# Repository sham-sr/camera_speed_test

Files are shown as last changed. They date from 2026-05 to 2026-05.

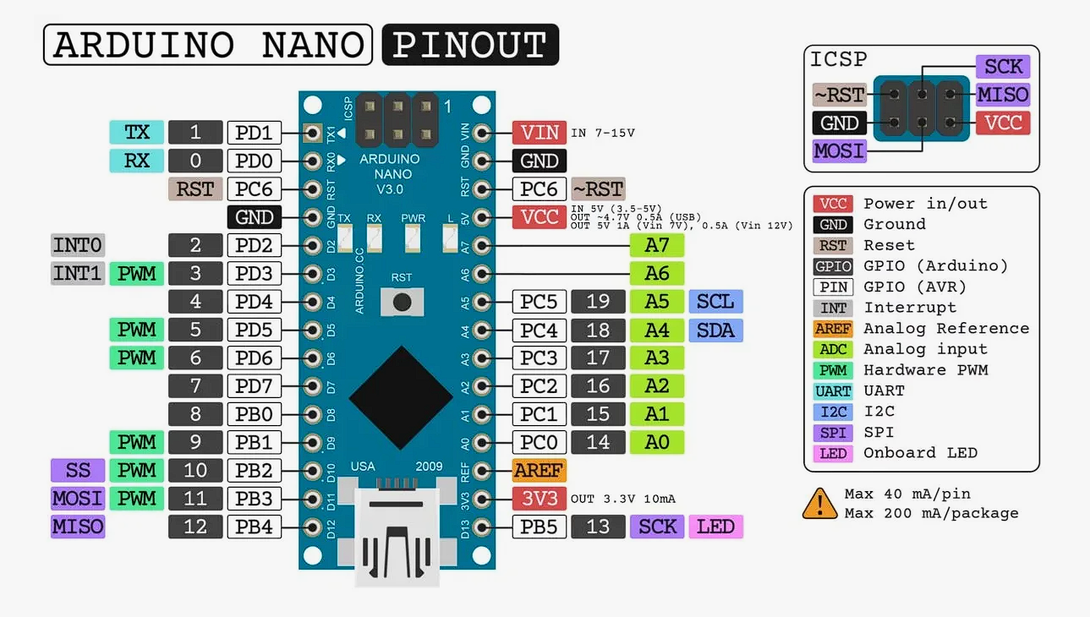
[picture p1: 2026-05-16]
hardware/nano v3 pins.png

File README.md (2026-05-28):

# fpv_g2g_latency

**Languages:** [English](README.en.md) · **Русский** (this page)

---

Прошивка для **Arduino Nano** (PlatformIO) — прибор для измерения задержки **glass‑to‑glass** в видеотракте «камера → транспорт (аналог / Ethernet / Wi‑Fi / RF) → монитор оператора». Стимул — биколорный LED, переключающийся между **красным** и **синим** (без полной темноты, чтобы автоэкспозиция камеры не «охотилась»). Фотоприёмник прижат к экрану монитора в светоизолирующей бленде. Экран прибора — **SSD1306 128×64** по I2C. Распайка — раздел [Распиновка](#распиновка) ниже.

## Распиновка

OLED **SSD1306 128×64** (I2C), кнопка, двухцветный светодиод, фотоприёмник на **A1**. Управление и логи также доступны через **USB / Serial** (`115200 8N1`) — прибор полностью работоспособен даже без OLED и без кнопки.

### SSD1306 128×64 (I2C)

Типичная маркировка выводов: **GND, VCC, SCL, SDA** (иногда порядок иной — сверяйте с шелкографией).

| Вывод модуля | Arduino Nano V3 | Примечание |
| --- | --- | --- |
| **GND** | **GND** | Общая земля |
| **VCC** | **5 V** *или* **3V3** | Часть модулей с преобразователем — **5 V**; чисто 3.3 В микросхема — только **3V3** (см. маркировку платы) |
| **SCL** | **A5** | Линия **SCL** шины `Wire` |
| **SDA** | **A4** | Линия **SDA** шины `Wire` |

Адрес I2C в коде по умолчанию **`0x3C`** (`cfg::kOledI2cAddress7bit` в `include/Config.h`). Если экран не отвечает — попробуйте **`0x3D`** или проверьте перемычку **ADDR** на плате.

Вывод **RST** на модуле, если есть, часто не тянут к МК — в `Config.h` задано **`kOledResetPin = -1`** (программный сброс по I2C).

**OLED не обязателен.** При отсутствии экрана в `include/Config.h` задайте **`kOledEnabled = false`** — прошивка не трогает I2C (A4/A5), зависаний на «висящей» шине не будет. Управление и логи — только Serial (см. раздел «Управление и наблюдение через Serial»). Когда подключите модуль — **`kOledEnabled = true`** и перепрошейте.

### Кнопка → **D2**

| Контакт кнопки | Nano |
| --- | --- |
| Один вывод | **D2**  |
| Другой вывод | **GND** |

`INPUT_PULLUP`: в покое **HIGH**, при нажатии **LOW**.

**Кнопка не обязательна.** Все жесты дублируются командами `m` / `c` / `r` / `h` из Serial.

### Двухцветный LED → **D4**, **D5**

Подразумевается **двухвыводный биколор** — два светодиода (красный/синий) встречно‑параллельно в одном корпусе. Ток в одном направлении — горит красный, в обратном — синий, без тока — оба погашены.

| Вывод LED | Подключение |
| --- | --- |
| Вывод **1** | **D4** |
| Вывод **2** | **D5** |

**Токоограничительный резистор** (например, **330 Ω**) ставится в разрыв **одного** из двух проводов — этого достаточно: ток в любую сторону всё равно проходит через тот же резистор. Двух резисторов не требуется.

| **D4** | **D5** | Результат |
| --- | --- | --- |
| `HIGH` | `LOW`  | Один цвет (Red в прошивке) |
| `LOW` | `HIGH` | Другой цвет (Blue в прошивке) |
| Одинаково (оба `LOW` или оба `HIGH`) | | Светодиод выключен |

Соответствие цветам задаётся в `BicolorLed::set`:

- `LedColor::Red`  → D4 = HIGH, D5 = LOW
- `LedColor::Blue` → D4 = LOW,  D5 = HIGH

Если по факту цвета визуально перепутаны — поменяйте местами провода D4/D5 (либо два `case` в `BicolorLed::set`). На корректность измерения это не влияет: знак `dirSign` рассчитывается автоматически по калибровке.

### Фотоприёмник → **A1**

Подойдёт любой из двух типов. Полярность (тёмно → высокий или низкий код АЦП) не критична: прошивка считает `cR`/`cB` и сама определяет, на какой «стороне» порога ждать каждое переключение.

#### Вариант A — фототранзистор NPN

Подтяжка **коллектора** через **10 кΩ** на **5 V**, эмиттер на **GND**. Сигнал с коллектора → **A1**.

- Темно → коллектор подтянут к 5 В → высокий код АЦП (≈ 1023)
- Ярче на датчике → коллектор просел → низкий код АЦП

#### Вариант B — фоторезистор (LDR)

LDR в делителе с подтяжкой **10 кΩ**. Включается одним из двух способов:

- LDR между **A1** и **5 V**, подтяжка **10 кΩ** от **A1** на **GND** → светло = **высокий** код.
- LDR между **A1** и **GND**, подтяжка **10 кΩ** от **A1** на **5 V** → светло = **низкий** код.

#### Механика

Фотоприёмник должен быть **прижат к экрану монитора в светоизолирующей бленде** (присоска, резиновая муфта, отрезок термоусадки и т. п.). Посторонняя засветка топит оба уровня (R и B сближаются) и автоматически ловится проверкой пригодности как `dRB low`.

### USB / Serial → встроенный преобразователь Nano (CH340 / FT232)

Подключается одним **USB‑кабелем** к ПК. На плате этот канал жёстко занимает два цифровых пина:

| Сигнал | Пин Nano | Назначение |
| --- | --- | --- |
| TX | **D1** | UART TX (USB ↔ ПК) |
| RX | **D0** | UART RX (USB ↔ ПК) |

- Скорость: **115 200 8N1**.
- Команды (один символ, регистр не важен): `m` — меню, `c` — калибровка, `r` — замер, `h` — справка.
- Все экраны дублируются строками с префиксами `[MENU]`, `[CAL]`, `[CAL_RESULT]`, `[WARMUP]`, `[LAT]`, `[RESULT]`, `[ABORT]`.

> `D0` и `D1` физически выведены на гребёнку Nano, но **не используйте** их под GPIO — это разорвёт Serial‑консоль.

### Сводная таблица пинов

| Пин | Назначение | Можно не подключать? |
| --- | --- | --- |
| **A4** | OLED SDA (I2C) | да (тогда — только Serial)  |
| **A5** | OLED SCL (I2C) | да |
| **D2** | Кнопка → GND | да (тогда — только Serial)  |
| **D4** | Биколор LED (вывод 1) | **нет** — это стимул |
| **D5** | Биколор LED (вывод 2) | **нет** — это стимул |
| **A1** | Фотоприёмник | **нет** — это датчик |
| **D0**, **D1** | USB‑Serial (RX/TX) | **нет** — нужны для консоли |
| **5 V**, **GND** | Питание периферии | — |

#### Минимальная рабочая конфигурация

Только то, без чего прибор измерять не может:

- **Биколор LED** на **D4/D5** (с одним токоограничивающим резистором)
- **Фотоприёмник** на **A1** (с подтяжкой 10 кΩ)
- **USB‑кабель** в ПК (питание + Serial)

OLED и кнопка — опциональны.

### Свободные пины для будущих модулей

Свободны (после вычета занятого выше): **D3**, **D6–D13**, **A0**, **A2–A3**, **A6–A7**.

- **D11**, **D12**, **D13** — это SPI (`MOSI / MISO / SCK`). Свободны под GPIO, но будут заняты при подключении SPI‑периферии.
- **A6**, **A7** на классическом Nano — **только АЦП**, без цифрового режима (нет порт‑регистра).

Свободного места достаточно для будущих расширений: дополнительный фотоприёмник, маркерный пин для логического анализатора (например, `D3` в кросс с фронтом смены цвета), внешний драйвер LED или потенциометр калибровки яркости.

## Сборка и прошивка

По умолчанию — **новый загрузчик** Optiboot (`nanoatmega328new`, 115200):

```bash
pio run -t upload
```

Перед записью прошивки выполняется **очистка flash** (`upload_flags = -e` в [`platformio.ini`](platformio.ini)): старый код и данные в EEPROM приложения сбрасываются, загрузчик на Nano остаётся. Чтобы ускорить повторные заливки при отладке — закомментируйте `upload_flags` в `platformio.ini`.

Старый загрузчик (редко):

```bash
pio run -e nanoatmega328 -t upload
```

Порт в [`platformio.ini`](platformio.ini): раскомментируйте `upload_port = /dev/ttyUSB1` (или свой `ttyUSB0` / `ttyACM0`).

### Ошибка `avrdude: stk500_getsync()`

| Причина | Что сделать |
|---|---|
| Не тот загрузчик | Сначала `pio run -t upload` (новый). Не помогло → `pio run -e nanoatmega328 -t upload` (старый, 57600). |
| Порт занят | Закройте Serial Monitor, `screen`, Arduino IDE, `minicom` на этом tty. |
| Нет прав на tty | `sudo usermod -aG dialout $USER`, перелогиньтесь; или разово `sudo pio run -t upload`. |
| Не тот кабель/порт | Только **data** USB; в `dmesg` должен быть `ch341` → `ttyUSB*`. |
| Нужен сброс | В момент «Uploading…» дважды быстро **RESET** на Nano (или удержать RESET, отпустить при старте загрузки). |

После успешной прошивки: `pio device monitor` (115200, как в прошивке).

## Стек

- **MCU:** ATmega328P (Arduino Nano)
- **Дисплей:** SSD1306 128×64 (I2C, `A4`/`A5`, адрес по умолчанию `0x3C` — см. `cfg::kOledI2cAddress7bit` в [`include/Config.h`](include/Config.h)). Шрифт по умолчанию 5×8 → ≈21 знак × 8 строк. **Не обязателен** — прибор полностью управляется и читается через Serial (см. ниже).
- **Serial-консоль:** `115200 8N1`, односимвольные команды (`m` / `c` / `r` / `h`), все экраны дублируются строками с префиксами `[MENU]`, `[CAL]`, `[RESULT]` и т. п. Подробнее — раздел «Управление и наблюдение через Serial».
- **Все рабочие параметры:** [`include/Config.h`](include/Config.h)

## Управление

| Жест | Действие из главного меню |
|---|---|
| Короткое одиночное | Выход из режима / обновление главного меню |
| Двойное короткое | Явная калибровка R / B (2 фазы × `kCalibPhaseDurationMs`) |
| Долгое удержание (≥ 3 с) | Авто‑прогрев и измерение задержки (`kLatencySessionMs`) |

Из любого экрана короткое одиночное возвращает в главное меню.

### Управление и наблюдение через Serial

Прибор полностью работоспособен и **без OLED** — все экраны дублируются в `Serial` (`115200 8N1`), а кнопка целиком заменяется однобуквенными командами. Можно даже физически не подключать дисплей.

Команды (нечувствительны к регистру, по одному символу, лишние пробелы/`\r`/`\n` игнорируются):

| Символ | Эквивалент жеста | Действие |
|---|---|---|
| `m` | Single | Возврат в главное меню / выход из любого режима |
| `c` | DoubleShort | Запуск явной калибровки R/B |
| `r` | LongHold | Запуск авто‑прогрева и измерения 15 с |
| `h` или `?` | — | Печать справки |

Жесты с **кнопки** и команды из **Serial** работают параллельно; что приходит первым в данном тике `loop()`, то и обрабатывается.

После старта в Serial выводится баннер и справка:

```
=== KRAN glass2glass: boot ===

--- KRAN glass2glass: serial console ---
commands (one char, case-insensitive):
  m  - menu / back / exit any screen
  c  - CALIBRATION (R/B, 2 phases x 5s)
  r  - RUN measurement (warmup + 15s R<->B)
  h  - this help
---
```

Каждый экран мирорируется одной строкой с префиксом в квадратных скобках:

```
[MENU]  m=back  c=cal(2ph x 5s)  r=run(22s, max~500ms)  h=help
[CAL] phase=1/2 RED  avg=812 mn=810 mx=814 sprd=4 n=320
[CAL] phase=2/2 BLUE avg=210 mn=208 mx=213 sprd=5 n=320

[CAL_RESULT] R=812 +/-4  B=210 +/-5  dRB=-602  status=OK
[WARMUP] phase=1/2  LED=RED
[WARMUP] phase=2/2  LED=BLUE
[LAT] t=0.3/22.5  n=0 lost=0  min=0.0 avg=0.0 max=0.0  RB=0.0 BR=0.0
[LAT] t=1.0/22.5  n=1 lost=0  min=42.3 avg=42.3 max=42.3  RB=42.3 BR=0.0
...
[LAT] t=22.5/22.5 n=28 lost=2  min=12.4 avg=42.7 max=78.1  RB=41.5 BR=43.9

[RESULT] GLASS->GLASS, ms:
  min  = 12.40
  avg  = 42.70
  max  = 78.10
  RB av= 41.50
  BR av= 43.10
  n    = 28
  lost = 2
```

Префиксы `[MENU]`, `[CAL]`, `[CAL_RESULT]`, `[WARMUP]`, `[LAT]`, `[RESULT]`, `[ABORT]` удобно фильтровать в логах (`grep`/`Select-String`) или парсить простыми скриптами для протоколов испытаний.

В случае отказа от измерения:

```
[ABORT] reason=dRB low  R=512  B=528  dRB=16
```

Команды, введённые пользователем, эхо‑печатаются префиксом `>>`:

```
>> [cmd] CALIBRATION
```

Так в логе виден и инициатор события, и его результат.

## Принцип измерения

1. **Сканер 2 фаз** (общий для калибровки и прогрева):
   - **RED** — LED красный, измеряется уровень `cR`.
   - **BLUE** — LED синий, измеряется уровень `cB`.

   Фоновая засветка отдельной фазой **не измеряется**: LED никогда не выключается во время сессии, а влияние фона на цветовые уровни автоматически вылавливается двумя проверками пригодности ниже.

2. **Расчёт порогов** между уровнями цветов (адаптивно от силы сигнала):
   - `mid = (cR + cB) / 2`
   - `H = clamp(|cR − cB| / kAdaptiveHysteresisSpreadDiv, kAdaptiveHysteresisMin … Max)` — при слабом луче на датчик (dRB≈12…30) порог ближе к `mid`
   - `tLow = mid − H`, `tHigh = mid + H`
   - `dirSign = sign(cB − cR)` — на какой «стороне» порога ожидать каждое переключение.
   - В Serial после калибровки/прогрева: `[CAL_THRESH] mid=… H=… tLo=… tHi=…`

3. **Проверка пригодности** перед измерением:
   - `|cR − cB| ≥ kFeasibleMinSpreadAdc` (по умолчанию **10**) — иначе `dRB low`
   - `|cR − cB| ≥ max(sprdR, sprdB) + kFeasibleSpreadAboveNoise` — разница цветов должна превышать шум фазы
   - `cR` и `cB` не в насыщении АЦП — иначе `ADC clip` (подкрутить подтяжку датчика / яркость монитора).
   - При отказе выводится экран **ABORT** с причиной и значениями уровней.

4. **Измерение R↔B** (`kLatencySessionMs`): LED переключается красный ↔ синий каждые `kLatencyBlinkHalfPeriodMs`. В момент команды на смену цвета фиксируется `t0 = micros()`; затем ожидается, что АЦП фотоприёмника пересечёт `mid` в нужную сторону (с гистерезисом). По первому пересечению — фиксируется `Δt`.

5. **Двусторонняя статистика**: задержки **R→B** и **B→R** учитываются раздельно (асимметрия Bayer/ISP/панели даёт разные значения).

## Пределы измерения и подбор параметров

Прибор измеряет задержку, ограниченную сверху **полупериодом стимула** и **таймаутом датчика**. Эти параметры выводятся из одной константы `cfg::kLatencyMaxExpectedMs` (мс):

```
kLatencyBlinkHalfPeriodMs = 1.5 × kLatencyMaxExpectedMs   // полупериод стимула
kLatencySensorTimeoutUs   = 1.2 × kLatencyMaxExpectedMs   // таймаут датчика на фронт
kLatencySessionMs         = max(15 с, 30 × полупериод)    // длительность сессии
```

Правило простое: **`kLatencyMaxExpectedMs` должен быть не меньше реальной задержки тракта**, иначе прибор начнёт либо терять выборки (если задержка больше таймаута), либо принимать «не свои» фронты (если задержка больше полупериода) → результат станет недостоверным.

### Готовые пресеты

Достаточно поменять одну строку в `include/Config.h`:

| Сценарий | `kLatencyMaxExpectedMs` | Полупериод | Таймаут | Сессия | Замечание |
|---|---|---|---|---|---|
| HDMI / низкозадержный аналог | `150` | 225 мс | 180 мс | 15 с | ~66 переключений |
| OpenIPC RTSP UDP локально | `300` | 450 мс | 360 мс | 15 с | ~33 переключения |
| **IP / RTSP / Wi‑Fi (по умолчанию)** | `500` | 750 мс | 600 мс | **22.5 с** | ~30 переключений |
| Wi‑Fi с большой буферизацией | `1000` | 1500 мс | 1200 мс | **45 с** | ~30 переключений |
| Экстремум (плохой WAN, много буферов) | `2000` | 3000 мс | 2400 мс | **90 с** | ~30 переключений |

### Что произойдёт, если задержка превысит `kLatencyMaxExpectedMs`

| Реальная задержка | Что увидите |
|---|---|
| ≤ `1.2 × max` | Норма, выборки захватываются |
| между `1.2 × max` и `1.5 × max` | Все или почти все выборки уходят в **`lost`**, финал с маленьким `n` или нулевым |
| > `1.5 × max` (т. е. больше полупериода) | **Алиасинг**: следующее переключение LED произойдёт ДО прихода фронта от текущего; пойдут ложные значения с заниженной задержкой и/или массовый `lost`. Доверять такому результату нельзя |

Поэтому, если в финале вы видите большое количество `lost` или подозрительно низкие значения при, по ощущениям, медленном тракте, — **поднимите** `kLatencyMaxExpectedMs` и перепрошейте.

### Можно ли менять только полупериод/таймаут вручную

Можно, но смысла мало — формулы простые и согласованные. Если хотите вручную: задайте свои значения и сохраняйте соотношения `таймаут < полупериод < ½ от среднего интервала между переключениями фронтов в тракте`.

## Что показывается на экране

Все экраны рассчитаны на 21 символ × 8 строк (SSD1306 128×64, шрифт по умолчанию).

### Глоссарий сокращений

| Сокращение | Полностью | Что значит |
|---|---|---|
| `R` | Red level | Среднее значение АЦП фотоприёмника, когда LED светит красным (0…1023) |
| `B` | Blue level | Среднее значение АЦП, когда LED светит синим (0…1023) |
| `sprd` / `+/-` | Spread | Разница `max − min` АЦП за фазу — грубая оценка шума/нестабильности освещения |
| `dRB` | Delta R↔B | Разница уровней `cB − cR` в кодах АЦП. Знак определяет `dirSign`. Чем больше по модулю — тем увереннее детектируется фронт |
| `mn` / `mx` | Min / Max | Минимальный и максимальный коды АЦП, наблюдавшиеся в текущей фазе |
| `n` | samples / count | Сколько отсчётов уже накоплено |
| `lost` | lost samples | Сколько переключений LED закончились **таймаутом** (фронт на датчике не пойман в окно ~200 мс) |
| `RB` | Red→Blue avg, ms | Средняя задержка перехода с красного на синий, миллисекунды |
| `BR` | Blue→Red avg, ms | Средняя задержка перехода с синего на красный, миллисекунды |
| `min/avg/max` | в финале/live | Минимум, среднее и максимум задержки по **всем** выборкам обоих направлений, в мс |

> Один код АЦП ≈ 5.0 В / 1024 ≈ **4.9 мВ** (опорное напряжение — `cfg::kAdcVrefVolts`).

---

### 1. Главное меню

```
KRAN  glass2glass
tap   = back
2tap  = CAL R/B
hold  = MEASURE

cal:  2ph x 5s
meas: 22s R<->B
max ~500ms
```

Значения времени и максимальной задержки **подтягиваются из `Config.h`** — если измените `kLatencyMaxExpectedMs`, экран и Serial обновятся автоматически.

| Строка | Что значит |
|---|---|
| `KRAN  glass2glass` | Заголовок прибора |
| `tap = back` | Короткое одиночное нажатие → возврат в меню / выход из режима |
| `2tap  = CAL R/B` | Два коротких подряд → **явная калибровка** (2 фазы по `kCalibPhaseDurationMs`) |
| `hold  = MEASURE` | Удержание ≥ 3 с → авто‑прогрев и **измерение** длиной `kLatencySessionMs` |
| `cal:  2ph x Ns` | Реальная длительность одной фазы калибровки |
| `meas: Ns R<->B` | Реальная длительность сессии замера и режим стимула |
| `max ~Nms` | Верхняя граница измеримой задержки (`kLatencyMaxExpectedMs`) |

---

### 2. Экран фазы калибровки

```
CAL 1/2  RED
adc   812
mn 810  mx 814
sprd  4
n     320

tap = menu
```

| Поле | Пример | Что значит |
|---|---|---|
| `CAL 1/2  RED` | 1/2, RED | Номер фазы и подпись: 1=RED, 2=BLUE |
| `adc 812` | 812 | Текущее **среднее** АЦП за фазу |
| `mn 810  mx 814` | 810 / 814 | Минимум и максимум АЦП в этой фазе (разница = шум/мерцание) |
| `sprd 4` | 4 | `mx − mn`. Маленький spread (< 10) — хороший признак, освещение стабильно. Большой (> 50) — есть мерцание / плохой контакт / посторонняя засветка |
| `n 320` | 320 | Сколько отсчётов уже взято в этой фазе (опрос каждые `kCalibSamplePeriodMs = 15 мс`) |
| `tap = menu` | — | Короткое нажатие прервёт калибровку и вернёт в меню |

Что должно получиться: `RED` → один стабильный уровень АЦП, `BLUE` → существенно другой. Если уровни почти одинаковые — на следующем экране будет `FAIL: dRB low`.

---

### 3. Итог калибровки

```
CAL  RESULT

R    812 +/-4
B    210 +/-5
dRB  -602

status: OK
tap = menu
```

| Поле | Пример | Что значит |
|---|---|---|
| `R 812 +/-4` | 812, spread 4 | Уровень при красном. Не должен быть в районе 0 или 1023 (насыщение) |
| `B 210 +/-5` | 210, spread 5 | Уровень при синем |
| `dRB -602` | -602 | `cB − cR`. Знак: тут отрицательное — значит красный ярче синего (`dirSign = -1`). По модулю 602 — отличный спред, измерение будет очень надёжным |
| `status: OK` | — | Спред ≥ 10, dRB выше шума фаз, без клиппинга АЦП |
| либо `FAIL: <reason>` | `dRB low` / `ADC clip` | Причина отказа (см. таблицу 5 «Экран ABORT») |

---

### 4. Экран авто‑прогрева перед замером

```
WARMUP
phase 1/2
LED   RED

checking R/B
levels ...

tap = menu
```

| Поле | Пример | Что значит |
|---|---|---|
| `WARMUP` | — | Идёт авто‑прогрев перед каждым измерением (2 фазы × `kWarmupPhaseDurationMs`, по умолчанию 2 × 2500 мс = 5 с) |
| `phase 1/2` | 1 | Номер фазы сканера 2 фаз |
| `LED RED` | RED | Текущий цвет LED в этой фазе (RED / BLUE) |
| `checking R/B levels …` | — | Идёт измерение уровней и проверка пригодности |
| `tap = menu` | — | Можно прервать прогрев и вернуться в меню |

После прогрева автоматически переход либо в **измерение**, либо в **ABORT**.

---

### 5. Экран ABORT — нельзя измерять

```
ABORT  no measure
reason: dRB low

R    512
B    528
dRB  16

tap = menu
```

| Поле | Пример | Что значит |
|---|---|---|
| `ABORT  no measure` | — | Прибор отказался начинать замер по результатам прогрева |
| `reason: <код>` | `dRB low` | Причина (см. таблицу ниже) |
| `R / B / dRB` | значения АЦП после прогрева | Диагностика — что именно увидел прибор |
| `tap = menu` | — | Возврат в меню |

Причины:

| reason | Что произошло | Что делать |
|---|---|---|
| `dRB low` | `|cR − cB| < 10` или разница не больше шума фазы | Улучшить попадание света на A1 (бленда, фокус); при dRB 12…18 смотреть `[CAL_THRESH]` — типично `H=2…3` |
| `ADC clip` | `cR` или `cB` ≤ 4 или ≥ 1019 — АЦП в насыщении | Уменьшить ток LED или подкрутить подтяжку фотодиода; снизить яркость монитора |
| `no data` | сканер не успел набрать выборки | Не должно случаться в норме; проверить опрос АЦП |

---

### 6. Live‑экран во время измерения

```
LAT 4.3/22.5
n 28  lost 1
min  12.4 ms
avg  42.7 ms
max  78.1 ms

RB 41.5  BR 43.9
tap = exit
```

| Поле | Пример | Что значит |
|---|---|---|
| `LAT 4.3/22.5` | 4.3 / 22.5 | Прошло секунд / всего секунд сессии (значение справа = `kLatencySessionMs / 1000`) |
| `n 28` | 28 | Накоплено валидных выборок (обоих направлений суммарно) |
| `lost 1` | 1 | Потеряно выборок (таймаут датчика > 200 мс — фронт не пойман) |
| `min  12.4 ms` | 12.4 мс | **Минимальная** задержка по всем выборкам обоих направлений |
| `avg  42.7 ms` | 42.7 мс | **Среднее** по всем выборкам |
| `max  78.1 ms` | 78.1 мс | **Максимум** (обычно ограничен размером кадра камеры и частотой обновления монитора) |
| `RB 41.5  BR 43.9` | 41.5 / 43.9 | Средние задержки отдельно по направлению `Red→Blue` и `Blue→Red` |
| `tap = exit` | — | Короткое нажатие прервёт замер и вернёт в меню |

Обновление OLED — ~4 раза в секунду (`kLatencyUiPeriodMs = 250 мс`), **только между фронтами** (пока ждём пересечение порога после переключения LED, дисплей и Serial не трогаются). Строки `[LAT]` в Serial — раз в секунду (`kLatencySerialPeriodMs`), чтобы не блокировать `loop()` при 115200. В каждом проходе `loop()` при ожидании фронта АЦП опрашивается до `kLatencySensorPollsPerLoop` раз. Если `lost` растёт быстро (десятки за пару секунд) — есть проблема: либо тракт уронил поток, либо камера/монитор не успевают за полупериодом стимула (750 мс при `max=500`).

---

### 7. Финальный экран `GLASS→GLASS`

```
GLASS->GLASS  ms
min  12.40
avg  42.70
max  78.10
RB   41.50
BR   43.10
n=240  lost=3
tap = menu
```

| Поле | Пример | Что значит |
|---|---|---|
| `GLASS->GLASS  ms` | — | Заголовок: все значения ниже — в **миллисекундах** |
| `min 12.40` | 12.40 мс | Минимальная задержка за сессию. Это «лучший случай», обычно соответствует моменту, когда переключение LED совпало с началом нового кадра камеры |
| `avg 42.70` | 42.70 мс | Среднее — основная характеристика, которую обычно записывают в протокол |
| `max 78.10` | 78.10 мс | Максимум — «худший случай», даёт представление о джиттере. Если `max − min` > 2/FPS камеры — нормально (кадровая дискретизация). Гораздо больше — есть джиттер в тракте (буферизация декодера, потери пакетов, vsync) |
| `RB 41.50` | 41.50 мс | Среднее по направлению `Red→Blue` |
| `BR 43.10` | 43.10 мс | Среднее по направлению `Blue→Red`. Разница 1–10 мс между `RB` и `BR` — норма (асимметрия Bayer/ISP/панели) |
| `n=240` | 240 | Сколько валидных выборок легло в статистику. Ожидаемое число выборок ≈ `kLatencySessionMs / kLatencyBlinkHalfPeriodMs`. При значениях по умолчанию (`max=500 мс`) это ~30 |
| `lost=3` | 3 | Сколько переключений завершились таймаутом. Доля `lost / (n + lost) < 5 %` — хорошо |
| `tap = menu` | — | Возврат в меню. Результат не сохраняется в EEPROM — только в RAM до перезагрузки/нового замера |

---

### Краткая шпаргалка «как читать результат»

| Что увидели | Как трактовать |
|---|---|
| `avg ≈ min ≈ max` | Тракт стабильный, без джиттера (редкость для IP/Wi‑Fi) |
| `max − min` ≈ 1–2 / FPS камеры | Нормальная кадровая дискретизация |
| `max ≫ avg` (в разы) | Буферизация в декодере / повторы пакетов в Wi‑Fi |
| `RB` сильно ≠ `BR` (> 15 мс) | Сильная асимметрия обработки цвета или панели; повторите замер с обмененными местами цветами или другим монитором |
| `lost` > 10 % | Слишком короткий полупериод для тракта, либо потери в линке. Увеличить `kLatencyBlinkHalfPeriodMs` |

## Хранение калибровки

Только **в RAM** (структура `app::CalibData`). При перезагрузке прибора калибровка теряется — это упрощает прошивку и гарантирует, что значения порогов соответствуют текущим условиям съёмки. Перед каждым измерением автоматически выполняется **короткий авто‑прогрев** (2 фазы по `cfg::kWarmupPhaseDurationMs`), который пересчитывает `cR / cB / mid` и принимает решение о пригодности.

## Что измеряется и что нет

Прибор измеряет **полную end‑to‑end задержку** видеотракта: оптика камеры → сенсор → ISP → кодировщик → транспорт → декодер → композитор → панель монитора → пиксель → фотодиод. Тракт может быть **любым** — аналоговым, IP, беспроводным.

В измерение **входит** время отклика ЖК панели, **не входит** только время самого МК на подачу команды (десятки микросекунд) — пренебрежимо мало по сравнению с типичными десятками миллисекунд тракта.

## Методика для повторяемых измерений

1. Прогреть камеру и монитор не менее 10 минут.
2. На камере зафиксировать экспозицию/усиление/баланс белого (например, в OpenIPC `majestic.yaml` — `exposure: manual`), отключить «динамические» обработки (HDR, шумодав, если возможно).
3. На мониторе зафиксировать яркость, отключить «динамический контраст» и «overdrive» (или зафиксировать профиль).
4. Прижать фотоприёмник к экрану монитора в бленде (без посторонней засветки), LED поместить в визирный кожух перед камерой (без бликов).
5. Сделать `2tap` — явную калибровку, убедиться, что `status: OK`.
6. Сделать долгое удержание — авто‑прогрев и замер. Повторить 5–10 раз.
7. Фиксировать в протоколе: `min / avg / max`, `RB`, `BR`, `n`, `lost`, конфигурацию тракта (кодек, разрешение, FPS, битрейт, транспорт, частота обновления монитора).

## Структура исходников

| Путь | Назначение |
|---|---|
| [`include/Config.h`](include/Config.h) | Все константы (пины, периоды, пороги пригодности) |
| [`include/Application.h`](include/Application.h) | Фазы, `CalibData`, оркестрация |
| [`src/Application.cpp`](src/Application.cpp) | Сканер 2 фаз (R/B), измерение R↔B, обработка жестов |
| [`include/DisplayUi.h`](include/DisplayUi.h), [`src/DisplayUi.cpp`](src/DisplayUi.cpp) | Все экраны под 21×8 |
| [`include/BicolorLed.h`](include/BicolorLed.h), [`src/BicolorLed.cpp`](src/BicolorLed.cpp) | Управление биколорным LED (Off/Red/Blue) |
| [`include/PhotoSensor.h`](include/PhotoSensor.h), [`src/PhotoSensor.cpp`](src/PhotoSensor.cpp) | Опрос АЦП фотоприёмника и накопление статистики |
| [`include/ButtonInput.h`](include/ButtonInput.h), [`src/ButtonInput.cpp`](src/ButtonInput.cpp) | Декодер жестов кнопки |
| [`include/SerialInput.h`](include/SerialInput.h), [`src/SerialInput.cpp`](src/SerialInput.cpp) | Декодер команд из Serial (эмулирует жесты кнопки) |

## Тесты и утилиты

См. [test/README.md](test/README.md) ([English](test/README.en.md)) — unit-тесты PlatformIO и утилита `phototransistor_screen_test.py` (стимул на экране монитора).

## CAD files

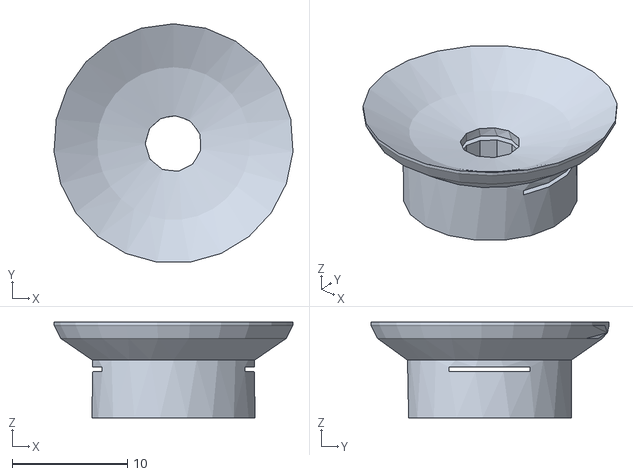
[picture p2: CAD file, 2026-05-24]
3d models/phototransistor 2.stl
20.7 x 20.7 x 8.29

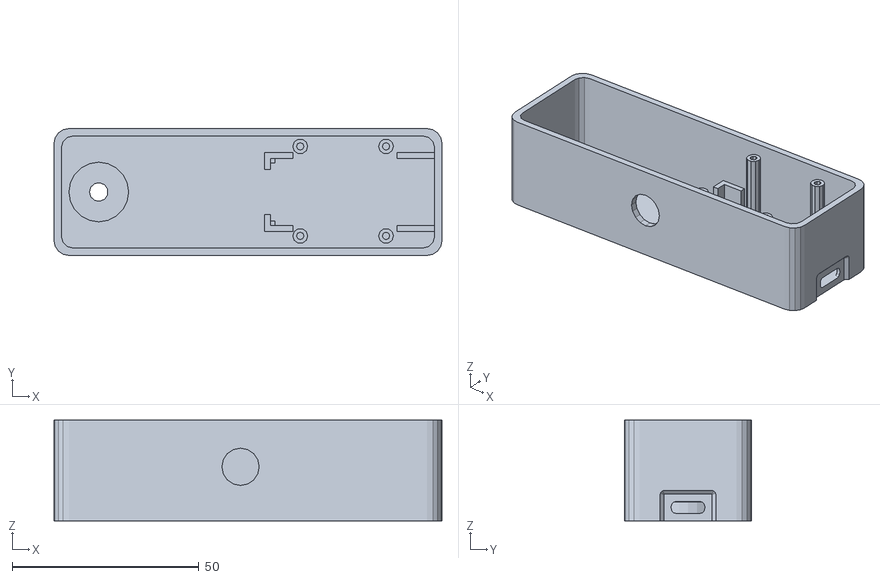
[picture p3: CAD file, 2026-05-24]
3d models/base.stl
104.0 x 34.0 x 27.0

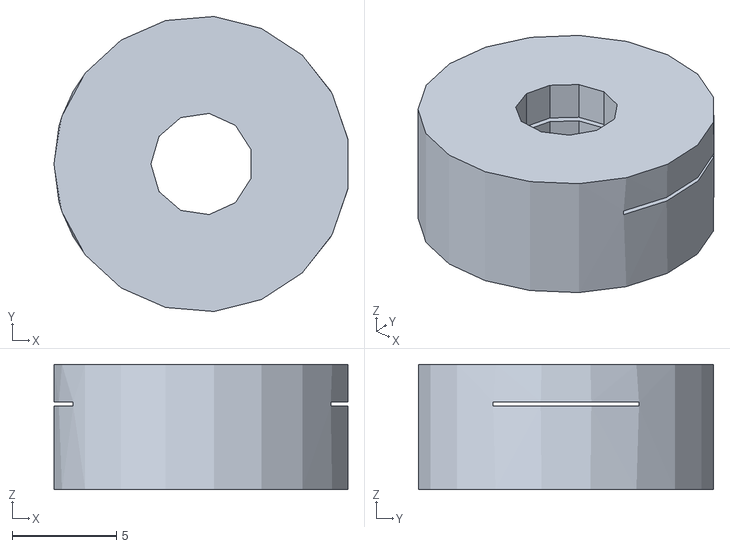
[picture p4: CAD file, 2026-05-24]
3d models/phototransistor.stl
14.1 x 14.2 x 6.00

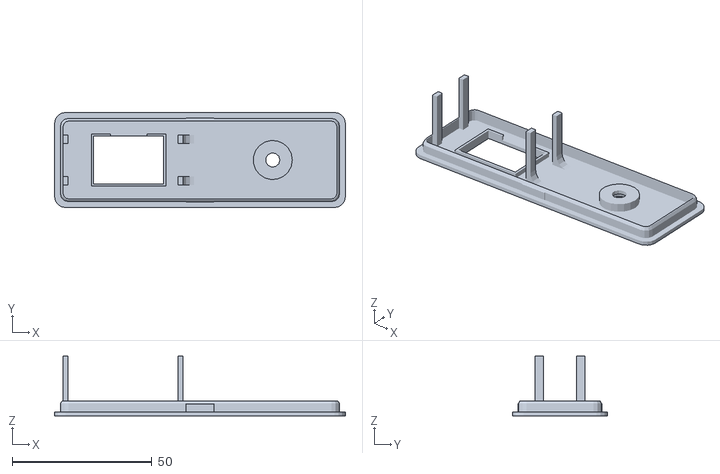
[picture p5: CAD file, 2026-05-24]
3d models/top.stl
104.0 x 34.0 x 21.4

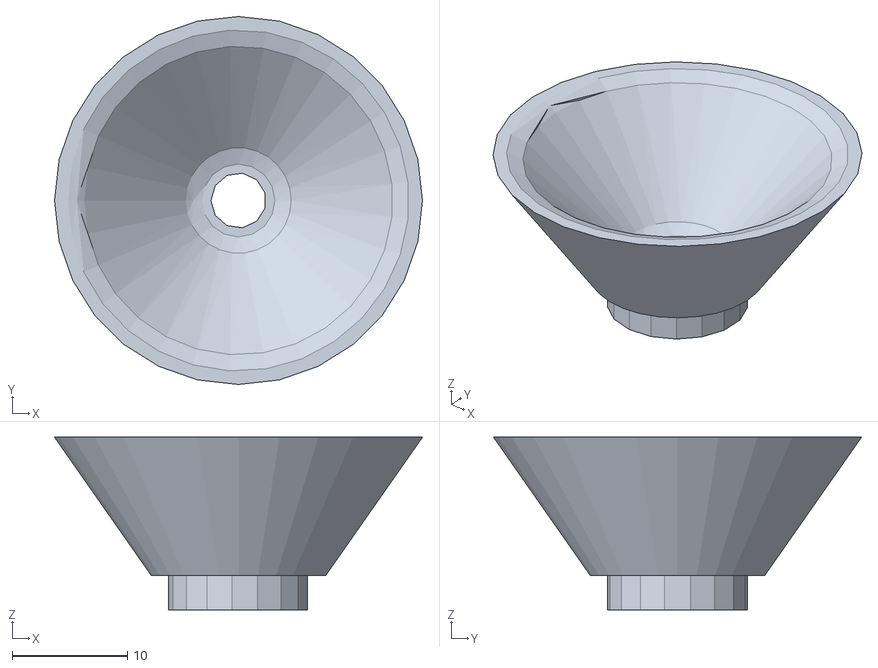
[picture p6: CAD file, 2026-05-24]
3d models/photodiod.stl
32.0 x 32.0 x 15.0

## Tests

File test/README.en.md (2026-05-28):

# Tests and helper utilities

**Languages:** **English** (this page) · [Русский](README.md)

---

## PlatformIO unit tests

The `test/` directory is for [PlatformIO unit tests](https://docs.platformio.org/en/latest/advanced/unit-testing/index.html).  
Firmware, calibration, and latency measurement: [README.md](../README.md) ([English](../README.en.md)) in the repository root.

---

## On-screen stimulus (`phototransistor_screen_test.py`)

Python utility in the project root: fullscreen red/blue stimulus on the monitor to verify the photodetector on screen. Timings and scenarios match the Arduino firmware (`include/Config.h`, `SerialInput.cpp`).

### Installation

```bash
python -m pip install -r requirements-screen-test.txt
```

Requires **Python 3** and **tkinter** (usually included with the standard Windows Python build). For Nano communication — **pyserial**.

### Run

```bash
python phototransistor_screen_test.py
```

Options:

- `--port COM7` or `--port /dev/ttyACM0` — pre-select port (Windows / Linux).
- `--windowed` — windowed mode instead of fullscreen.

### Controls

Same commands as the firmware Serial Monitor (115200):

| Key | Serial | Action |
|-----|---|---|
| **m** | `m` | Menu, cancel, screen off |
| **c** | `c` | Calibration: 5 s red + 5 s blue |
| **r** | `r` | Warmup 2.5+2.5 s, then R↔B measurement |
| **h** / **?** | `h` | Help |
| **Esc** | — | Quit |

When a COM port is selected, the key is sent to the device and **in parallel** the local on-screen stimulus runs.

The **Serial** block in the window mirrors firmware lines (`[CAL]`, `[CAL_RESULT]`, `[ABORT]`, `[LAT]`, `[RESULT]`, etc.). If the device reports **`status=FAIL`** (e.g. `dRB low`) or **`[ABORT]`**, the local stimulus **stops** — measurement on screen does not continue, same as on the Arduino.

### Ports (Windows / Ubuntu)

Refresh the port list with **“Refresh”**. **“(none — screen only)”** — run without Arduino.

On Linux, if access is denied: `sudo usermod -aG dialout $USER` and log in again.

### Screen delay

Slider **“Delay (measurement only)”**: **5 ms** steps, ±500 ms range. Shifts color changes **only in the measurement phase** (emulates picture lag relative to the LED). Warmup and calibration from Arduino run **without offset**.

### Timings (defaults in `Config.h`)

| Mode | Duration |
|---|---|
| Calibration | 2× 5000 ms (R, B) |
| Warmup | 2× 500 ms (R, B) |
| Measurement | half-period 750 ms, session 22.5 s |

When you change `kLatencyMaxExpectedMs` in firmware, update the same constants at the top of `phototransistor_screen_test.py`.

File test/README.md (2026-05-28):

# Тесты и вспомогательные утилиты

**Languages:** [English](README.en.md) · **Русский** (this page)

---

## PlatformIO unit tests

Каталог `test/` — для [unit-тестов PlatformIO](https://docs.platformio.org/en/latest/advanced/unit-testing/index.html).  
Прошивка, калибровка и замер задержки: [README.md](../README.md) ([English](../README.en.md)) в корне репозитория.

---

## Стимул на мониторе (`phototransistor_screen_test.py`)

Python-утилита в корне проекта: полноэкранный красный/синий стимул на мониторе для проверки фотоприёмника на экране. Тайминги и сценарии совпадают с прошивкой Arduino (`include/Config.h`, `SerialInput.cpp`).

### Установка

```bash
python -m pip install -r requirements-screen-test.txt
```

Нужны **Python 3** и **tkinter** (в стандартной сборке Python для Windows обычно уже есть). Для связи с Nano — **pyserial**.

### Запуск

```bash
python phototransistor_screen_test.py
```

Опции:

- `--port COM7` или `--port /dev/ttyACM0` — предвыбор порта (Windows / Linux).
- `--windowed` — без полноэкранного режима.

### Управление

Те же команды, что в Serial Monitor прошивки (115200):

| Клавиша | Serial | Действие |
|---|---|---|
| **m** | `m` | Меню, отмена, экран выкл. |
| **c** | `c` | Калибровка: 5 с красный + 5 с синий |
| **r** | `r` | Прогрев 2,5+2,5 с, затем замер R↔B |
| **h** / **?** | `h` | Подсказка |
| **Esc** | — | Выход |

При выбранном COM-порте в шапке окна символ уходит на устройство и **параллельно** запускается локальный стимул.

В блоке **Serial** в окне дублируются строки прошивки (`[CAL]`, `[CAL_RESULT]`, `[ABORT]`, `[LAT]`, `[RESULT]` и т.д.). Если устройство сообщает **`status=FAIL`** (например `dRB low`) или **`[ABORT]`**, локальный стимул **останавливается** — замер на экране не продолжается, как на Arduino.

### Порты (Windows / Ubuntu)

Список портов обновляется кнопкой **«Обновить»**. Пункт **«(нет — только экран)»** — работа без Arduino.

На Linux при ошибке доступа: `sudo usermod -aG dialout $USER` и перелогин.

### Задержка экрана

Ползунок **«Задержка (только замер)»**: шаг **5 мс**, диапазон ±500 мс. Сдвигает только смену цвета **в фазе замера** (эмуляция запаздывания картинки относительно LED). Прогрев и калибровка с Arduino идут **без сдвига**.

### Тайминги (по умолчанию в `Config.h`)

| Режим | Длительность |
|---|---|
| Калибровка | 2× 5000 мс (R, B) |
| Прогрев | 2× `kWarmupPhaseDurationMs` (R, B), по умолчанию 2× 2500 мс |
| Замер | полупериод 750 мс, сессия 22,5 с |

При изменении `kLatencyMaxExpectedMs` в прошивке те же константы нужно обновить в начале `phototransistor_screen_test.py`.

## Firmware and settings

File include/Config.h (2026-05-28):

#pragma once

#include <Arduino.h>

// Параметры измерения задержки «стекло—стекло» и OLED SSD1306 128×64 (I2C) на Arduino Nano.
// Схема: ARD <-> LED (R/B) перед камерой; фотоприёмник, прижатый к экрану монитора.
// Измеряем задержку переключения цвета LED → отображение цвета на мониторе.

namespace cfg {

// --- Пины (см. README.md, раздел «Распиновка») -----------------------------

static constexpr uint8_t kPinButton = 2;     // Кнопка → GND, INPUT_PULLUP
static constexpr uint8_t kPinLedA = 4;       // Биколор LED
static constexpr uint8_t kPinLedB = 5;
static constexpr uint8_t kPinPhotoAdc = A1;  // Фотоприёмник

// --- OLED SSD1306 I2C (по умолчанию Wire: SDA=A4, SCL=A5 на Nano) ----------

// false — OLED не подключён: Wire/I2C не трогаем (нет зависаний на «висящей» шине).
// true  — модуль на A4/A5; при отсутствии ответа остаётся только Serial.
static constexpr bool kOledEnabled = true;

static constexpr uint8_t kDisplayWidth = 128;
static constexpr uint8_t kDisplayHeight = 64;

// Адрес модуля: чаще 0x3C, реже 0x3D (перемычка на плате).
static constexpr uint8_t kOledI2cAddress7bit = 0x3C;

// -1: вывод RST не используется (типичный модуль с общим сбросом).
static constexpr int8_t kOledResetPin = -1;

// Частота I2C, Гц (400 кГц — быстрее обновление; при длинных проводах попробуйте 100000).
static constexpr uint32_t kOledI2cClockHz = 400000UL;

// Таймаут операций Wire (мкс), если ядро Arduino поддерживает WIRE_HAS_TIMEOUT.
static constexpr uint32_t kOledWireTimeoutUs = 2500UL;

// Параметры шрифта по умолчанию (5x8) с межсимвольным пикселем: 6x8.
// На экране 128x64 умещается 21 символ x 8 строк — учитывается при вёрстке UI.
static constexpr uint8_t kCharsPerLine = 21;
static constexpr uint8_t kLinesPerScreen = 8;

// --- Опрос и ввод ------------------------------------------------------------

static constexpr unsigned long kButtonDebounceMs = 45UL;
static constexpr unsigned long kDoubleClickMaxGapMs = 420UL;
static constexpr unsigned long kLongPressMs = 3000UL;
static constexpr unsigned long kShortPressMaxMs = 800UL;

// --- Сканер 2 фаз: общий движок для калибровки и авто-прогрева --------------
// Порядок фаз: 0 — Red, 1 — Blue. Без Off-фаз: фоновый уровень не требуется,
// проверка пригодности обходится только по самим R/B (см. ниже).
static constexpr uint8_t       kScanPhaseCount = 2;
static constexpr unsigned long kCalibPhaseDurationMs = 5000UL;  // длинная калибровка
static constexpr unsigned long kCalibPhaseSettleMs   = 1200UL;  // не учитывать выборки после смены LED
static constexpr unsigned long kCalibSamplePeriodMs  = 15UL;
static constexpr unsigned long kWarmupPhaseDurationMs = 2500UL; // авто-прогрев перед замером
static constexpr unsigned long kWarmupPhaseSettleMs   = 700UL;
static constexpr unsigned long kWarmupSamplePeriodMs  = 10UL;
static constexpr unsigned long kScanUiPeriodMs = 250UL;

// Робастная оценка уровня/шума по гистограмме АЦП (перцентили, без min/max по выбросам).
static constexpr uint8_t kAdcHistBins = 64;
static constexpr uint8_t kHistPercentileLow  = 10;  // «mn» и нижняя граница шума
static constexpr uint8_t kHistPercentileMid  = 50;  // уровень cR/cB
static constexpr uint8_t kHistPercentileHigh = 90;  // «mx» и верхняя граница шума

// --- Измерение задержки -----------------------------------------------------
// В измерении только R<->B (без Off), чтобы стабилизировать AE/AGC камеры
// и измерять чистое время реакции цепи камера → транспорт → монитор.
//
// ГЛАВНЫЙ ПАРАМЕТР — ожидаемая верхняя граница задержки тракта (мс).
// Из него автоматически выводятся полупериод стимула, таймаут датчика и
// длительность сессии. Меняйте, если ваш тракт заведомо медленнее.
//
// Типовые значения:
//   150  — HDMI / низкозадержный аналог
//   300  — OpenIPC RTSP UDP локально
//   500  — IP / RTSP / Wi-Fi                       ← по умолчанию
//   1000 — Wi-Fi с большой буферизацией
//   2000 — экстремум (плохой WAN, много буферов)
//
// Правила, на которых построены формулы ниже:
//   - Полупериод > задержки, иначе следующее переключение случится ДО прихода
//     фронта от текущего → алиасинг и ложные выборки.
//   - Таймаут датчика < полупериода (чтобы освободить ожидание перед сменой LED).
//   - Сессия — не меньше 15 с И не меньше ~30 переключений (по 15 в каждую сторону).
static constexpr unsigned long kLatencyMaxExpectedMs = 500UL;

// Полупериод: 1.5x от ожидаемого максимума (запас 50%).
static constexpr unsigned long kLatencyBlinkHalfPeriodMs =
    (kLatencyMaxExpectedMs * 3UL) / 2UL;

// Таймаут датчика: 1.2x от ожидаемого максимума, гарантированно < полупериода.
static constexpr unsigned long kLatencySensorTimeoutUs =
    (kLatencyMaxExpectedMs * 12UL / 10UL) * 1000UL;

// Длительность сессии: max(15 с, 30 полных переключений).
static constexpr unsigned long kLatencySessionMs =
    (kLatencyBlinkHalfPeriodMs * 30UL > 15000UL)
        ? (kLatencyBlinkHalfPeriodMs * 30UL)
        : 15000UL;
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

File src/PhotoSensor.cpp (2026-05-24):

#include "PhotoSensor.h"

namespace hw {

void PhotoSensor::begin() {
  pinMode(cfg::kPinPhotoAdc, INPUT);
}

uint16_t PhotoSensor::readCode() const { return analogRead(cfg::kPinPhotoAdc); }

float PhotoSensor::codeToVolts(uint16_t code) const {
  return static_cast<float>(code) * (cfg::kAdcVrefVolts / cfg::kAdcMaxCode);
}

void PhotoSensor::resetStats(AdcStats *s) {
  if (s == nullptr) {
    return;
  }
  s->minCode = 1023;
  s->maxCode = 0;
  s->sumCount = 0;
  s->sumCodes = 0;
}

void PhotoSensor::accumulate(AdcStats *s, uint16_t code) {
  if (s == nullptr) {
    return;
  }
  if (code < s->minCode) {
    s->minCode = code;
  }
  if (code > s->maxCode) {
    s->maxCode = code;
  }
  s->sumCodes += code;
  s->sumCount += 1;
}

float PhotoSensor::averageVolts(const AdcStats &s) {
  if (s.sumCount == 0) {
    return 0.0F;
  }
  const float avgCode = static_cast<float>(s.sumCodes) / static_cast<float>(s.sumCount);
  return avgCode * (cfg::kAdcVrefVolts / cfg::kAdcMaxCode);
}

void PhotoSensor::resetHist(AdcHist *h) {
  if (h == nullptr) {
    return;
  }
  for (uint8_t i = 0; i < cfg::kAdcHistBins; i++) {
    h->counts[i] = 0;
  }
}

void PhotoSensor::accumulateHist(AdcHist *h, uint16_t code) {
  if (h == nullptr) {
    return;
  }
  const uint8_t bin = static_cast<uint8_t>(
      (static_cast<uint32_t>(code) * cfg::kAdcHistBins) / 1024U);
  const uint8_t idx = (bin >= cfg::kAdcHistBins) ? static_cast<uint8_t>(cfg::kAdcHistBins - 1U)
                                                   : bin;
  h->counts[idx]++;
}

namespace {

uint16_t histPercentileCode(const hw::AdcHist &h, const uint32_t total,
                            const uint8_t percentile) {
  if (total == 0U) {
    return 0U;
  }
  uint32_t target = (total * static_cast<uint32_t>(percentile) + 50U) / 100U;
  if (target < 1U) {
    target = 1U;
  }
  uint32_t cum = 0U;
  for (uint8_t i = 0; i < cfg::kAdcHistBins; i++) {
    cum += h.counts[i];
    if (cum >= target) {
      const uint16_t binLow =
          static_cast<uint16_t>((static_cast<uint32_t>(i) * 1024U) / cfg::kAdcHistBins);
      const uint16_t binHigh =
          static_cast<uint16_t>((static_cast<uint32_t>(i + 1U) * 1024U) / cfg::kAdcHistBins);
      return static_cast<uint16_t>((binLow + binHigh) / 2U);
    }
  }
  return 1023U;
}

}  // namespace

RobustStats PhotoSensor::computeRobust(const AdcHist &h) {
  RobustStats out{};
  uint32_t total = 0U;
  for (uint8_t i = 0; i < cfg::kAdcHistBins; i++) {
    total += h.counts[i];
  }
  out.sampleCount = total;
  if (total == 0U) {
    return out;
  }
  out.pLow = histPercentileCode(h, total, cfg::kHistPercentileLow);
  out.pHigh = histPercentileCode(h, total, cfg::kHistPercentileHigh);
  out.level = histPercentileCode(h, total, cfg::kHistPercentileMid);
  out.spread = (out.pHigh >= out.pLow) ? static_cast<uint16_t>(out.pHigh - out.pLow) : 0U;
  return out;
}

}  // namespace hw

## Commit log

2026-05-16 Enhance backlight control logic in DisplayUi and update configuration settings. Added options for PWM usage and active state for backlight, along with troubleshooting tips in pins.md.
2026-05-16 Refactor project for STM32F103C8 «Blue Pill» support, updating pins.md, README.md, and configuration files. Adjusted pin assignments for peripherals, enhanced display handling in DisplayUi, and remov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
2026-05-17 Refactor project to support SSD1306 display, updating pins.md, README.md, and configuration files. Enhanced display handling in DisplayUi, improved calibration logic, and added detailed troubleshooti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
2026-05-19 Enhance ADC calibration logic by implementing adaptive hysteresis for threshold calculations. Update README.md with detailed calibration steps and feasibility checks. Adjust configuration parameters 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
    [Application.cpp, Config.h, DisplayUi.cpp]
2026-05-20 Refactor OLED handling in DisplayUi and update configuration parameters. Change `kOledEnabled` to control I2C interactions based on OLED connection status. Adjust `platformio.ini` for default toolcha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
2026-05-24 Remove pins.md as its content is now integrated into README.md under the "Распиновка" section. Update platformio.ini to change upload and monitor ports. Refactor ADC handling in Application and Photo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
    [base.stl, photodiod.stl, phototransistor 2.stl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]
2026-05-24 Add latency measurement enhancements in Application
    - Introduced new methods `latencyPollEdge` and `latencyRefreshLiveUi` for improved latency handling.
    - Refactored `tickLatency` to streamline the latency measurement process and UI updates.
    - Updated `Config.h` with a new constant for ADC polling during latency measurement.
    - Adjusted comments in `DisplayUi` to clarify the OLED display behavior during latency measurements.
2026-05-24 Update platformio.ini and README.md for flash cleaning and calibration phase adjustments
    - Added `upload_flags` to `platformio.ini` for full flash erase before programming.
    - Updated README.md to reflect changes in flash cleaning process and calibration phases, clarifying the new two-phase calibration and warmup procedures.
    - Refactored comments in `Application.h` and `Application.cpp` to align with the updated calibration logic and LED handling.
2026-05-28 Enhance README.md with language options and additional testing utilities section. Update latency handling in Application and DisplayUi to improve serial logging and sensor polling. Refactor configura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
2026-05-28 Update README files to rename project from 'camera_speed_test' to 'fpv_g2g_latency' for clarity and consistency across language versions.
